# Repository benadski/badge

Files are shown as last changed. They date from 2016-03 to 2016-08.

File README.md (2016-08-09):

# Fri3d Camp Badge

Elk zichzelf respecterend hacker/maker/DIY kamp, _moet_ een eigen badge hebben. Zo ook Fri3d Camp :-)

## Concept

Bij het ontwerp van de badge voor Fri3d Camp zijn we vertrokken van drie principes:

1. Een hoge _hack_-baarheid.
2. Leerzaam voor beginners.
3. Interactief.

Daarom brengt de badge het Arduino platform samen met infra-rode stralen om een eenvoudig Fri3d Camp draadloos (IR) netwerk te maken.

Het Arduino platform laat iedereen toe om de software van de badge aan te passen, of er iets totaal anders mee te doen. Naast de badge-functie voor Fri3d Camp, brengen we alle andere mogelijke functionaliteit van de microcontroller naar buiten, zodat de badge, na het kamp, letterlijk kan dienen als jouw eigen Arduino ontwikkel-bord.

Aan de hand van de IR componenten en bijhorende software kunnen de elementaire aspecten van draadloze communicatie uitgelegd worden.

### Meta-Leerzaam

Dit ontwerp is mijn eerste SMD-gebaseerde project en het is op zich al een leerzame ervaring. Daarom bevat deze repository tevens een [design dagboek](design/dagboek.md) waarin ik alle stappen van het proces beschrijf.

## Hardware Design

Twee bestaande projecten kunnen beschouwd worden als de spreekwoordelijke ouders van de badge: 

* [Arduino Pro Micro - 3.3V/8MHz van Sparkfun](https://www.sparkfun.com/products/12587)
* [TV B Gone van Mitch Altman](https://cornfieldelectronics.com/tvbgone/tvbg.home.php)

Voeg nog een IR receiver en een RGB LED toe en je hebt alle basis componenten voor een leerzame, interactieve en zeer _hack_-bare Fri3d Camp badge!

## Software

Om zelf aan de slag te gaan met de [software](src/README.md) zo eenvoudig mogelijk te maken, was één van dé belangrijkste aspecten een makkelijke integratie met het Arduino software platform. De mogelijkheid om de badge te programmeren via de Arduino IDE door middel van louter een micro-USB kabel was daarom een noodzaak.

Om het Arduino platform nog verder zo veel mogelijk te gebruiken, hebben we ook gekozen om zo dicht mogelijk bij een bestaand Arduino bord te blijven en zo is de badge in essentie een [Arduino Mirco](https://www.arduino.cc/en/Main/ArduinoBoardMicro) geworden.

Je kan dus onmiddellijk aan de slag, zoals met elke andere Arduino. Daarnaast bevat deze [repository](src/README.md) enkele applicaties specifiek geschreven voor de Fri3d Camp badge, en dit naast een bibliotheek die het aanspreken van de extras makkelijk maakt. Zo vindt je (weldra) hier:

* dé Fri3d Camp 2016 app
* een implementatie van de TV B Gone applicatie van Mitch Altman
* ...

Als je zelf een nieuwe app maakt die op de Fri3d Camp badge werkt en op een andere, leuke manier gebruik maakt van de IR communicatie en de RGB LED of van andere componenten die je er zelf aan toegevoegd hebt, bezorg ons dan deze code en we voegen ze toe aan deze repository (pull request).

## Credits

De badge werd ontworpen door Christophe VG, samen met de hele Fri3d Camp organisatie, en uitgewerkt met de hulp van Dragan Subotic, Yannick Verbelen, Maarten Weyn, Willy De a Court, Anthony Liekens, Dries Deroeck, Jef Van Den Broeck, Toon Van de Putte,...

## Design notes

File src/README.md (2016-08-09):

# Fri3d Camp Badge Software

In deze sectie van de Fri3d Camp Badge repository vind je alle
software-gerelateerde zaken, gaande van de bootloader tot verschillende Arduino
sketches die je stap voor stap leren werken met de Fri3d Badge.

## Bootloader

Zonder een [bootloader](bootloader/), kan je zelf moeilijk aan de slag via de Arduino IDE.

## Alive

De eerste Arduino sketch die op onze badge werkte en aangaf dat ze werkte: It's [alive](alive/).

## TV B Fri3d

Niet op zijn minst als eerbetoon aan Mitch Altman en zijn TV B Gone, de Arduino implementatie ervan op de Fri3d Badge: [TV B Fri3d](tv-b-fri3d)!

## Examples

Als je de `Fri3dBadge/` folder kopieert (of linkt) in je sketch folder, kan je alle examples rechtstreeks in je Arduino IDE openen en op de Fri3d Camp Badge laden.

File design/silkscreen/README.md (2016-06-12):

# Adding Logo's to the Silkscreen

```bash
$ make
convert rombit.png -colors 2 -type bilevel +antialias rombit.bmp
convert fri3d.pdf fri3d.png
convert fri3d.png -colors 2 -type bilevel +antialias fri3d.bmp
rm fri3d.png
```

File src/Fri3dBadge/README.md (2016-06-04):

This folder should go in your Sketchbook/libraries folder. You can do this
using a symbolic link:

```bash
$ ln -s `pwd`/src/Fri3dBadge ~/Documents/Arduino/libraries/
```

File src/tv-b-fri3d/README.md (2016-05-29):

# TV B Fri3d

Aangezien de [TV B Gone](http://cornfieldelectronics.com/tvbgone/tvbg.home.php) één van de spreekwoordelijks ouders is van de Fri3d Badge, kan een implementatie van deze software niet ontbreken.

Het gebruiken van een Arduino om een "TV B Gone" te maken, is ook het onderwerp van een workshop van Mitch Altman zelf (zie: [http://cornfieldelectronics.com/cfe/projects/tvbg_arduino/tvbg_arduino_workshop.php](http://cornfieldelectronics.com/cfe/projects/tvbg_arduino/tvbg_arduino_workshop.php) voor meer info).

Deze versie is gebaseerd op eerder werk door Ken Shirriff. Mitch Altman heeft de code verder aangepast voor meerdere Arduino platformen, o.a. voor de "Adafruit's Flora", welke ook werkt op basis van de ATMega32u4.

## Aanpassingen

De code werkt niet "out-of-the-box" op de Fri3d Badge. Ze compileert prima,  maar we moeten nog wel enkele aanpassingen doen, omdat we andere pinnen (kunnen) gebruiken om de verschillende LEDs aan te sturen. Enerzijds is er de aansturing van de IR LEDs en anderszijds is er de status LED.

#### IR LED

In het geval van de Fri3d Badge is de pin om de IR LEDs aan te sturen (`IR_TX`) voorzien op pin `PF6`. In de code is ondersteuning voor Arduino/ATmega32u4 digitale pinnen "Digital Pin 3" of "Digital Pin 11" voorzien. Deze komen respectievelijk overeen met pin 18, `PD0`, en pin 12, `PB7 `(zie [https://www.arduino.cc/en/Hacking/PinMapping32u4](https://www.arduino.cc/en/Hacking/PinMapping32u4))

De code die hier relevant is:

```c
...
    // Fast PWM, setting top limit, divide by 8
    // Output to pin 3
#ifdef __AVR_ATmega32U4__
  #if (IRLED == 11)
    TCCR0A = _BV(COM0A1) | _BV(COM0A0) | _BV(WGM01) | _BV(WGM00);
  #elif (IRLED == 3)
    TCCR0A = _BV(COM0B1) | _BV(COM0B0) | _BV(WGM01) | _BV(WGM00);
  #else
    #error "IR LED must be on Leonardo digital pin 3 or 11."
  #endif
...  
```

Nader onderzoek leert dat dit tevens de twee pinnen zijn die op de ATmega32u4 kunnen gebruikt worden in een opstelling met `Timer0`. Zie [http://r6500.blogspot.be/2014/12/fast-pwm-on-arduino-leonardo.html](http://r6500.blogspot.be/2014/12/fast-pwm-on-arduino-leonardo.html), sectie over 'Single Slope PWM':
>Timer 0 has two compare channels A and B associated to two compare registers OCR0A and OCR0B. The two channels are linked to two hardware outputs OC0A and OC0B that are used as Arduino pins numbers 11 and 3.

Aangezien de Arduino implementatie voor de ATmega32 Beide pinnen zijn in ons design nog beschikbaar, zal het dus neerkomen op een aanpassing van het schema en de layout. Aangezien dit van de onderkant naar de bovenkant van de layout moet, zal het dus langs de onderkant moeten doorlopen. Gegeven de huidige layout, lijkt `PD0`, "Digital Pin 3", de beste keuze.

#### Status LED

The TV B Gone uses a status LED to indicate what it's doing. We don't have a simple LED on Fri3d Badge, but we have an RGB LED ;-)

De code die hier relevant is:

```c
// This function quickly pulses the visible LED (connected to PB0, pin 5)
// This will indicate to the user that a code is being transmitted
void quickflashLED( void ) {
  digitalWrite(LED, HIGH);
  delay_ten_us(3000);   // 30 millisec delay
  digitalWrite(LED, LOW);
}
```

Hier gaan we de RGB LED gebruiken, dus de code "moet" structureel aangepast worden, en drie verschillende pinnen aansturen. Oops, ook hier lopen we opnieuw _bijna_ tegen een slechte voorbereiding op: om de drie kleuren/pinnen te controleren hebben we opnieuw 3 PWM kanalen nodig. Gelukkig zijn de drie pinnen (`RGB_REG`, `RGB_GREEN` en `RGB_BLUE`) net aangesloten op drie pinnen met PWM support on "Digital Pins 5, 10 en 9". Een snelle test moet dit weldra bevestigen.

Wordt vervolgd...

## Fri3d Badge op Fri3d Camp 2016

Mitch Altman komt met zijn "Arduino for newbies" workshop naar Fri3d Camp, en wie weet werken jullie wel met jullie eigen badge tijdens deze workshop ;-) We sturen onze aanpassingen in ieder geval naar hem door ;-)

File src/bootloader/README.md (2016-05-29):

# Fri3d Camp Badge Bootloader

Een bootloader zorgt er voor dat de eerste software die op de microcontroller
de microcontroller toegankelijk maakt om er nieuwe software op te zetten zonder
een volledige programmerinfrastructuur. Concreet laat de Arduino bootloader toe
om via de Arduino IDE software te installeren op de microcontroller via de USB
kabel.

## Selecteren

Er zijn verschillende booloaders voor Arduino, maar slechts enkele komen in aanmerking voor onze microcontroller, de ATmega32u4.

We zijn vertrokken van de Arduino Micro Pro 3.3V vertrokken. Deze module werd ontworpen door Sparkfun en ze stellen ook een bootloader ter beschikking voor deze modules. We kunnen ze daarom ook hergebruiken. De bootloader voor deze module is een versie van de "caterina" bootloader.

Alle verschillende bootloaders zijn te vinden via [https://github.com/sparkfun/Arduino_Boards/tree/master/sparkfun/avr/bootloaders/caterina](https://github.com/sparkfun/Arduino_Boards/tree/master/sparkfun/avr/bootloaders/caterina)

Voorlopig hebben we na wat proberen gekozen voor de bootloader van de "[LilyPad USB](https://www.sparkfun.com/products/12049)". Deze module is ook gebaseerd op de ATmega32u4 en gebruikt ook de 3.3V opstelling aan 8MHz. Mogelijk zijn andere bootloaders ook mogelijk. We bekijken dit nog, maar voorlopig werkt deze keuze prima :-)

## Installeren

De Makefile in deze folder automatiseert de installatie aan de hand van de Atmel JTAGICE MkII programmer. Ze stuurt `avrdude` aan. Installatie van een bootloader vraagt twee stappen:

1. Het instellen van de `fuses` zodat de bootloader kan ingesteld worden.
2. Het effectief uploaden van de bootloader en het blokkeren ervan.

Wanneer je de Arduino IDE geïnstalleerd hebt, beschik je over een `boards.txt` bestand. Daarin vind je alle instellingen om de verschillende microcontrollers te programmeren. Je kan de instellingen die wij hier gebruiken ook hierin terugvinden:

Bv op Mac OS X kan je in de `Arduino.app` bundle het `boards.txt` bestand terugvinden als `Arduino.app/Contents/Java/hardware/arduino/avr/boards.txt`. Hierin vind je bv. een sectie over de Lilypad USB:

```
LilyPadUSB.bootloader.tool=avrdude
LilyPadUSB.bootloader.low_fuses=0xff
LilyPadUSB.bootloader.high_fuses=0xd8
LilyPadUSB.bootloader.extended_fuses=0xce
LilyPadUSB.bootloader.file=caterina-LilyPadUSB/Caterina-LilyPadUSB.hex
LilyPadUSB.bootloader.unlock_bits=0x3F
LilyPadUSB.bootloader.lock_bits=0x2F
```

We zien hier inderdaad dat de LilyPad voldoet aan onze mogelijkheden:

```
LilyPadUSB.build.mcu=atmega32u4
LilyPadUSB.build.f_cpu=8000000L
```

In het `boards.txt` bestand vinden we niet direct een andere module terug die de `atmega32u4` combineert met `8MHz`. Normaal gezien zou een "Arduino Micro Pro 3.3V" ook moeten lukken, maar dat is voorlopig nog niet bewezen ;-)

Om te installeren (met de zelfde programmer en instellingen als wij) volstaat een gewone `make`:

```bash
 make
*** unlocking MCU
!!! please toggle the power of the programmer
    Press any key to continue...
*** uploading bootloader
```

Normaal gezien zou de tussentijse reset van de programmer niet nodig mogen zijn, maar voorlopig geeft deze procedure de stabielste werking.

De twee commando's die onderliggend al het werk doen zijn:

```bash
$ avrdude -c jtag2isp -p atmega32u4 -P usb:5a:cb -b 19200 -e -U efuse:w:0xce:m -U hfuse:w:0xD8:m -U lfuse:w:0xFF:m -U lock:w:0x3f:m
$ avrdude -c jtag2isp -p atmega32u4 -P usb:5a:cb -b 19200 -e -U flash:w:Caterina-lilypadusb.hex -U lock:w:0x2F:m
```

## Zie ook ...

* [Arduino Hacking - Bootloader](https://www.arduino.cc/en/Hacking/Bootloader?from=Tutorial.Bootloader)
* [Sparkfun Tutorial on installing a bootloader](https://learn.sparkfun.com/tutorials/installing-an-arduino-bootloader)

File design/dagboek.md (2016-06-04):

# Design Dagboek

Aangezien dit [mijn](http://christophe.vg) eerste SMD-gebaseerde ontwerp is, zal het een fijne leerschool worden. Daarom wil ik deze hier documenteren, voor mezelf, maar ook voor iemand anders die het ook wel eens van naderbij wil bekijken.

## Klaar? ... Start ... Leer!

Ik heb gekozen voor
[Eagle](http://www.cadsoftusa.com/eagle-pcb-design-software/about-eagle/), de de facto standaard editor voor PCB ontwerp. De [gratis versie](http://www.cadsoftusa.com/download-eagle/freeware/) biedt alle mogelijkheden, met beperkingen waar je niet snel tegen loopt als beginner. De software is tevens beschikbaar voor alle courante platformen (Windows, Linux, Max OS X), wat niet het geval is met de meeste concurrenten.

Software kiezen is één, er mee werken... Gelukkig zijn er zeer goeie tutorials online te vinden:

* [https://learn.sparkfun.com/tutorials/how-to-install-and-setup-eagle](https://learn.sparkfun.com/tutorials/how-to-install-and-setup-eagle)
* [https://learn.sparkfun.com/tutorials/using-eagle-schematic](https://learn.sparkfun.com/tutorials/using-eagle-schematic)
* [https://learn.sparkfun.com/tutorials/using-eagle-board-layout](https://learn.sparkfun.com/tutorials/using-eagle-board-layout)
* [https://learn.sparkfun.com/tutorials/designing-pcbs-advanced-smd](https://learn.sparkfun.com/tutorials/designing-pcbs-advanced-smd)

## De schouders van reuzen

Het wiel uitvinden is al lang niet meer nodig in het koninkrijk van electronica. Er zijn heel veel designs te vinden die allemaal een deel van de puzzel kunnen zijn. Zo ben ik ook vertrokken van enkele grote puzzelstukken en heb die bij elkaar gebracht.

### Arduino Micro Pro 3.3V

De basis van het ontwerp is de Arduino Micro Pro in de versie die op 3.3V werkt. Deze bevat alle minimale eisen die we stelden aan het ontwerp, in een redelijk eenvoudig samen te stellen geheel. De microcontroller, de ATMEGA32u4, bevat USB connectiviteit, waardoor eenvoudige ondersteuning voor de Arduino IDE en programmaring mogelijk wordt.

[https://www.sparkfun.com/products/12587](https://www.sparkfun.com/products/12587)

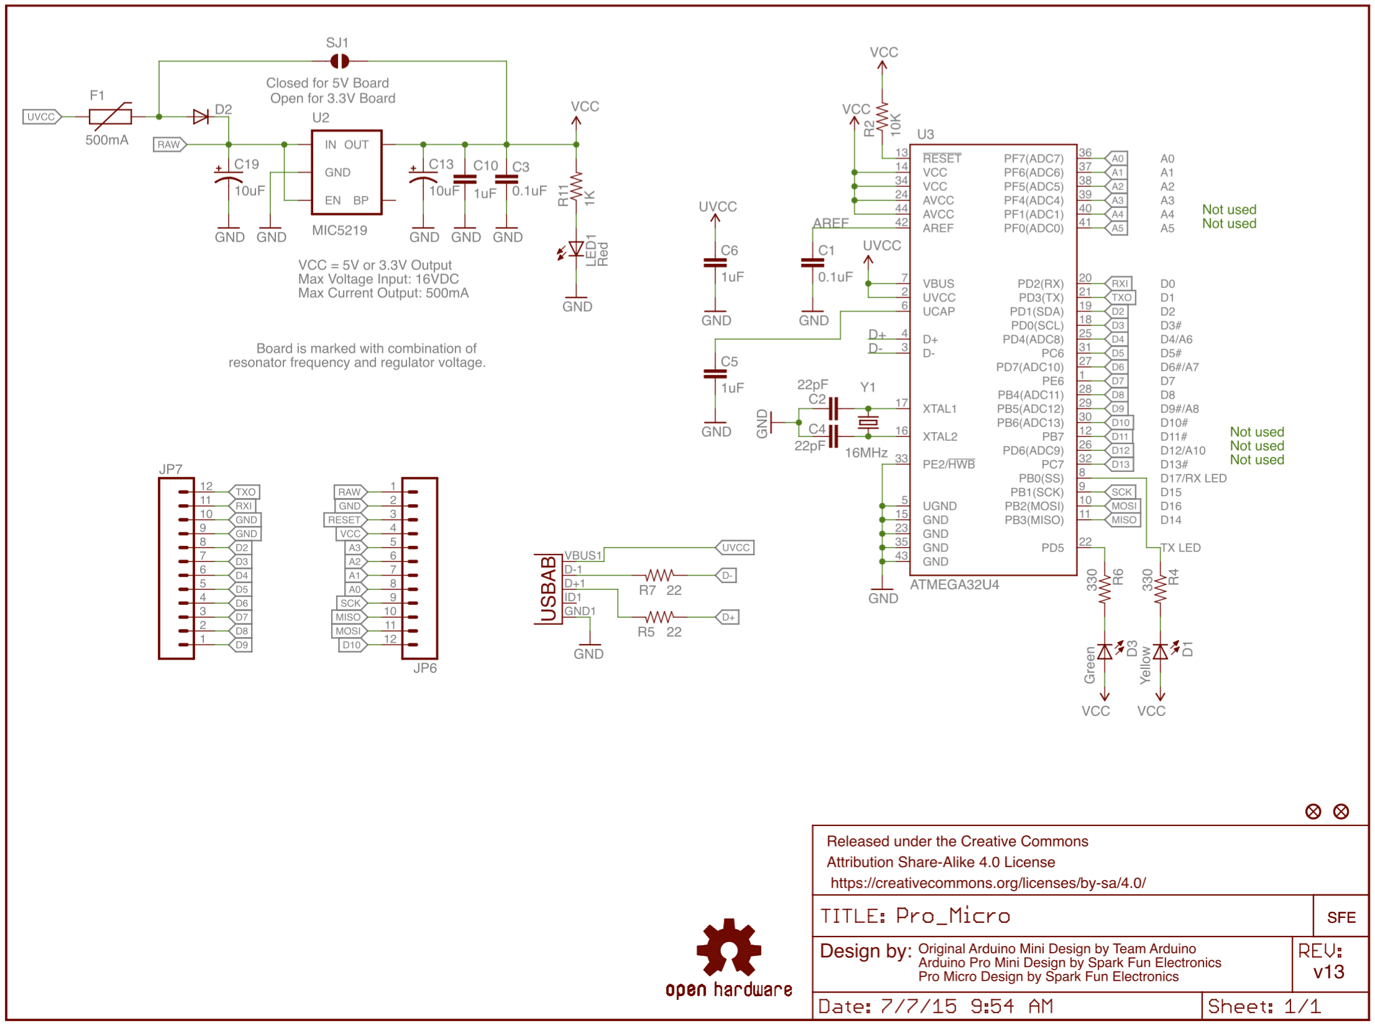
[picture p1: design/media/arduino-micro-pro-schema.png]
Arduino Micro Pro


### TV B Gone

De initiële plannen om een draadloze netwerk-verbinding te incorporeren, strandden toen we de prijzen zagen voor de RF modules. Gelukkig bestaat er een "goedkoop" alternatief, die relatief dezelfde technologie introduceert, op een veel eenvoudigere en betaalbare manier: infra-rode (IR) stralen.

En als we aan IR denken, komen we al snel uit bij Mitch Altmans TV B Gone. Deze IR zendende oplossing kan prima dienen als referentie design voor deze functionaliteit.

[https://learn.adafruit.com/tv-b-gone-kit/download](https://learn.adafruit.com/tv-b-gone-kit/download) 

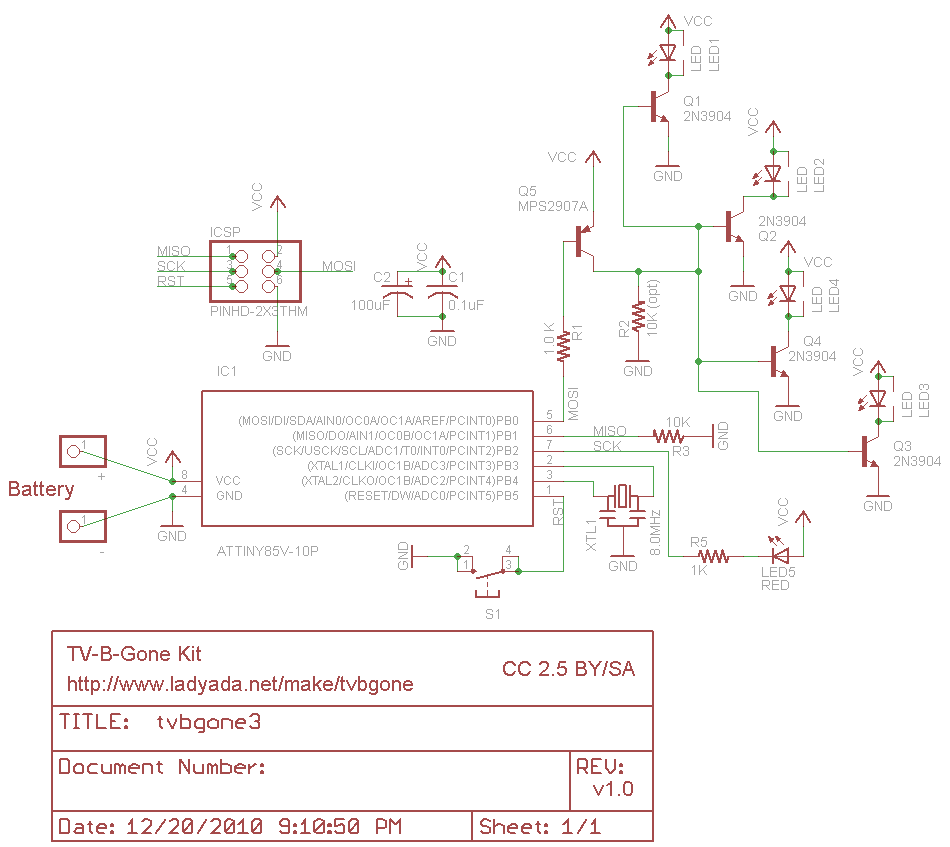
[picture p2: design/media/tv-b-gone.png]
TV B Gone


### LiPo oplaad circuit

De IR LEDs trekken al snel een stroom die boven de mogelijkheden liggen van een coin cell batterij. We konden gaan voor 2 AAA batterijen, maar dan wordt de badge al snel log en zwaar. Daarom proberen we bij het initiële design te vertrekken van een herlaadbare LiPo batterij.

Om deze te kunnen opladen, hebben we een integratie nodig met de inkomende USB voeding. Gelukkig bestaat ook daarvoor een bijna de facto oplossing en is ook het omringende oplaad-circuit mooi gedocumenteerd.

[https://learn.sparkfun.com/tutorials/lipo-usb-charger-hookup-guide](https://learn.sparkfun.com/tutorials/lipo-usb-charger-hookup-guide)

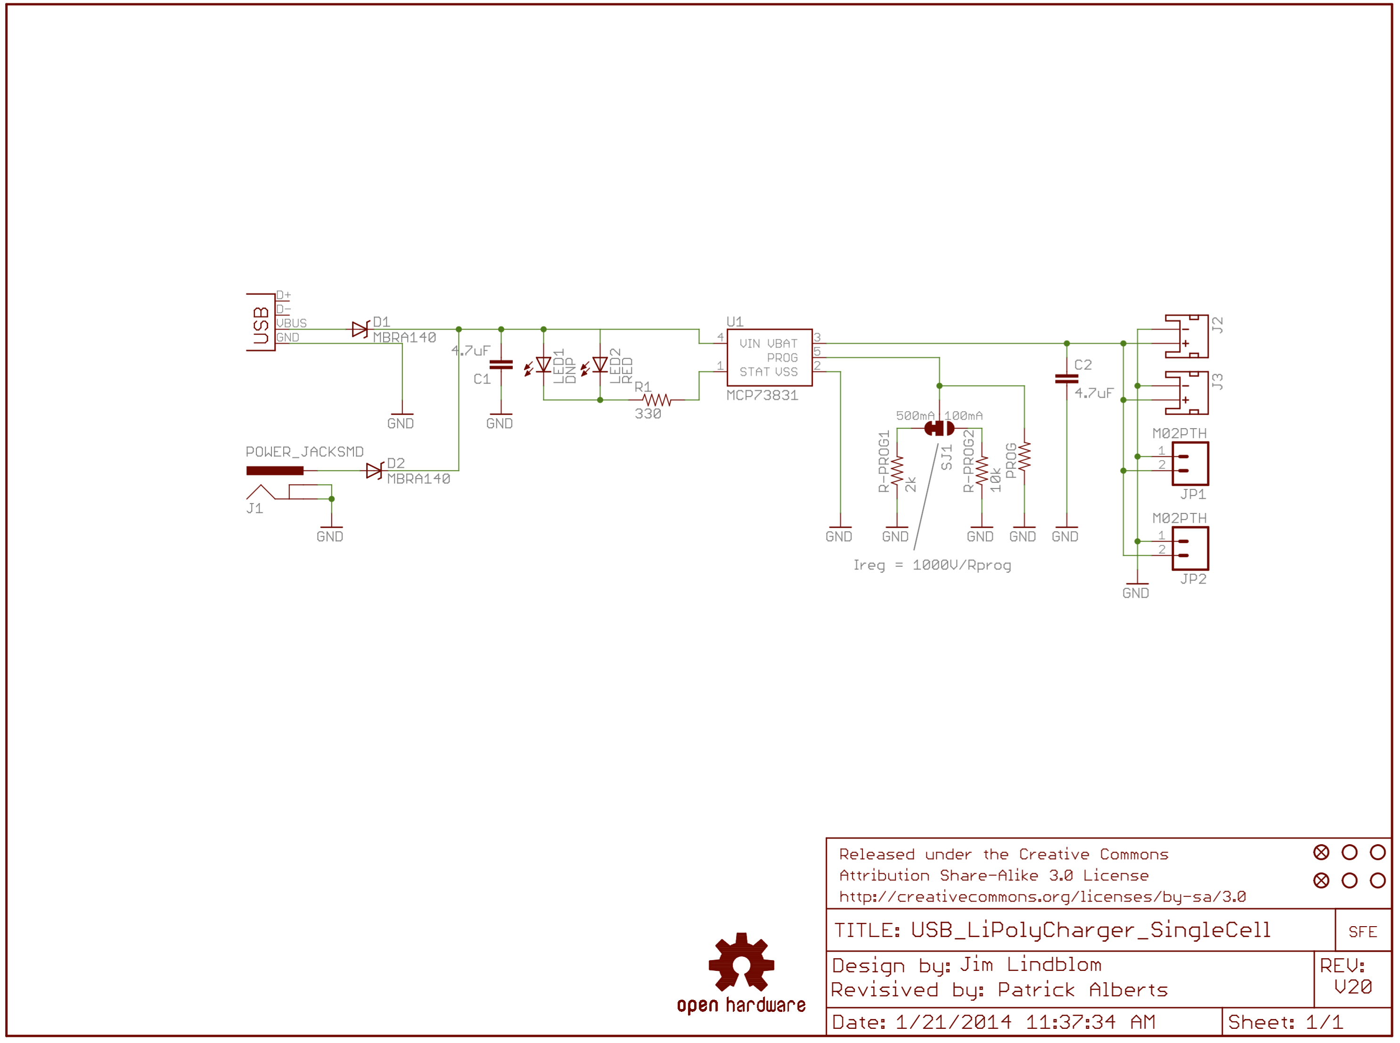
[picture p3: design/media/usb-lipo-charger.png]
USB LiPo Charger


### Fri3d Badge Schema versie 1

De combinatie van de drie voorgaand vermelde referentie designs, gecombineerd met nog een knopje, RGB LED en IR ontvanger, levert ons ...

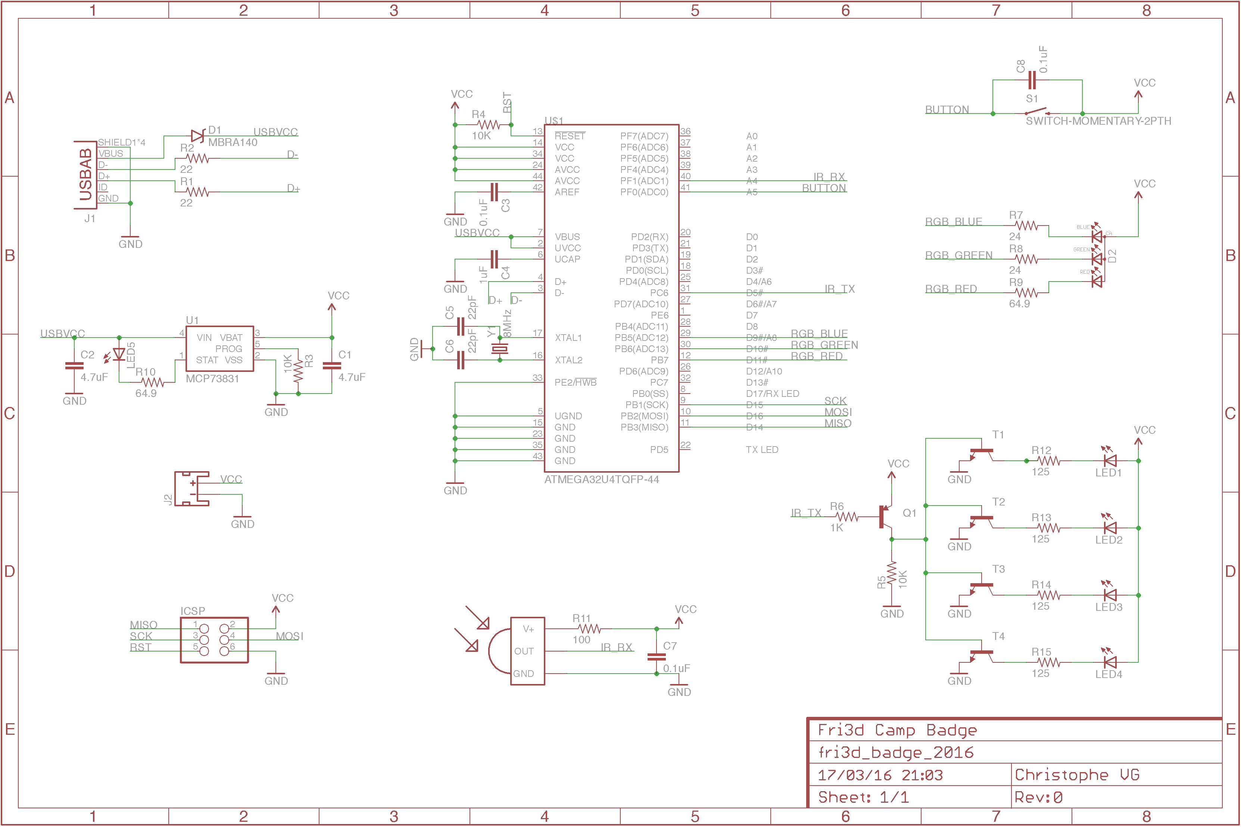
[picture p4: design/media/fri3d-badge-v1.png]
Fri3d Badge Schema versie 1


## Eerste optimalisaties

Met versie 1 onder de arm op naar enkele hulplijnen. Met het oog op zo veel mogelijk automatisering van de productie, zijn enkele aspecten zeer belangrijk:

1. Hoe minder componenten, hoe minder er kan fout gaan.
2. Hoe minder verschillende componenten, hoe meer dat er geautomatiseerd kan verlopen.

Met dat motto in gedachte werden volgende aanpassingen aan versie 1 doorgevoerd:

1. Vervanging van de PNP + NPN constructie voor de IR LEDs door een enkele N-channel MOSFET.
2. Vervanging van weerstanden door combinaties van dezelfde weerstanden (e.g. 2 weerstanden van 220&ohm; in parallel is ongeveer gelijk aan één van 100&ohm; enz)
3. Enkele fouten en redundante componenten werden bijgewerkt/verwijderd.

### Fri3d Badge Schema versie 2

En dat levert ons een versie op waarmee ik aan de slag kan om de layout van de PCB te maken...

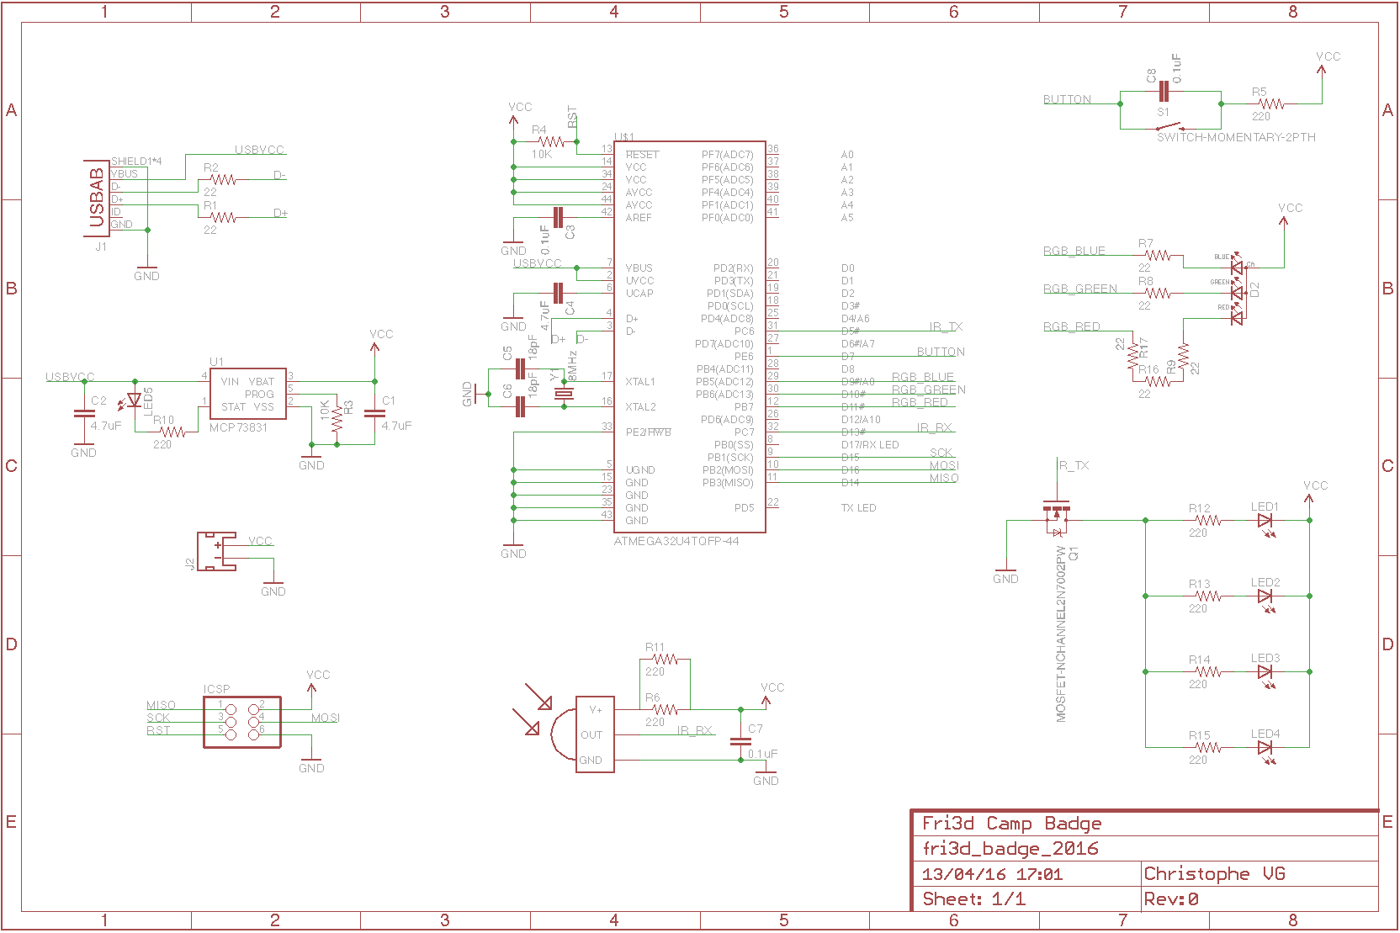
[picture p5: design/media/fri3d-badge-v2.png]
Fri3d Badge Schema versie 2


## PCB Layout

De Fri3d Badge heeft op het eerste zicht al één belangrijke eigenschap: zijn vorm is geen klassieke PCB-vorm, want we willen ze de vorm geven van het logo.

Na het tekenen van de omtrek ga je aan de slag om de componenten een plek te geven. Hierbij probeer je zo veel mogelijk logische blokken te maken en het aantal kruisende lijnen (air wires) te minimaliseren.

De PCB zal opgebouwd worden uit twee lagen, de voor- en achterkant van de badge. Op de achterkant komt hoofdzakelijk de oplaadbare batterij en de bijhorende connector. Centraal op de voorkant komt de microcontroller en daarrond de verschillende functionele componenten: IR LEDs, IR receiver, RGB LED, knop, laadcircuit, USB connector, ICSP connector.

Na een avondje zwoegen kom je dan, met wat hulp, tot een eerste PCB layout:

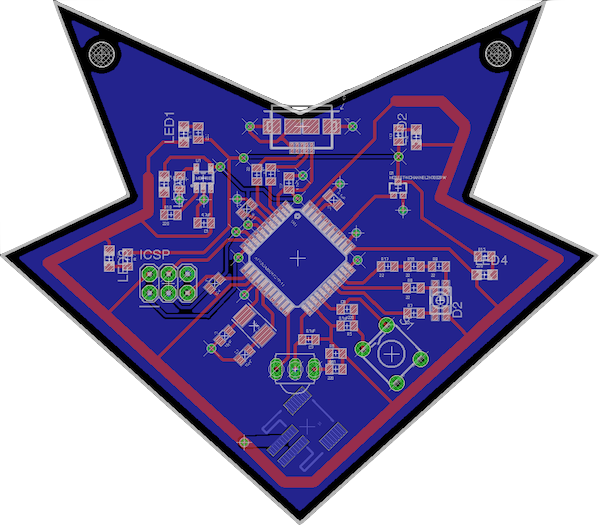
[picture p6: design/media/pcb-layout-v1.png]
Fri3d Badge Layout versie 1


Enkele tips:

* Creëer op de onderkant een groot vlak en verbindt dit met GND. Nu hoef je van de bovenkant slechts een via te maken en je hebt directe toegang tot de GND. Zie het grote blauwe vlak op de layout hierboven.
* De zelfde truc kan je bij een meer-dan-twee lagen PCB ook doen voor VCC, maar die luxe hebben we hier niet. Daarom truc nr. 2: maak een dikke VCC-omranding! Niet meer gewoon te bereiken met een via, maar wel langs een kort baantje naar de buitenzijde van de PCB.

### Eerste Prototype(s)

En dan is het tijd om de virtuele wereld van Eagle te verlaten en echte prototypes te maken. Met een koffer vol componenten trokken we naar het electronica-lab van de Erasmus Hoge School om zelf PCBs te etsen en te voorzien van componenten - een hele onderneming.

**Wordt vervolgd...**

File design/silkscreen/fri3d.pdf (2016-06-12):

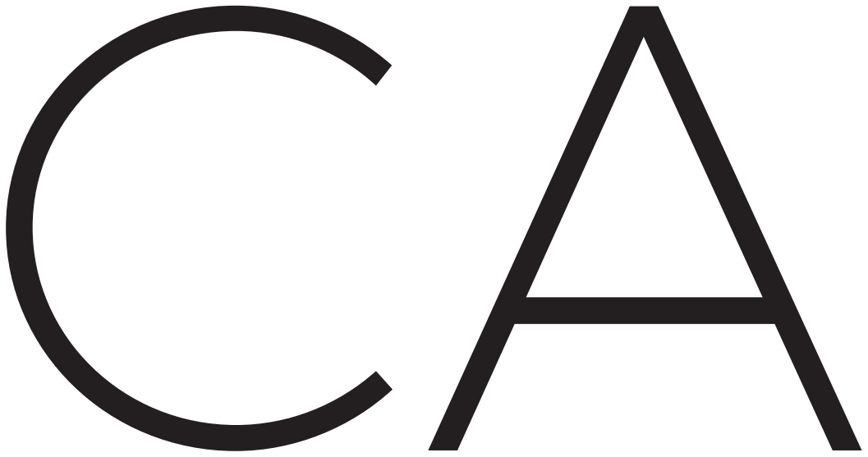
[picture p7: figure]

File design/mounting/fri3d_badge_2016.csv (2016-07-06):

%,Origin,Offset,X,Y,,
% theoretical offset 7,7
65535,0,5.5,6.5,,
%,Stack,Offset,Stack,X,Y,
% offsets for MCU in tray
% x = -8.8 + 6 = -2.8
% y=   8.6 - 6 =  2.6
65535,1,0,-2.8,2.6,
65535,1,1,0,0,
65535,1,2,0,0,
65535,1,3,0,0,
65535,1,4,0,0,
65535,1,5,0,0,
65535,1,6,0,0,
65535,1,7,0,0,
65535,1,8,0,0,
65535,1,9,0,0,
65535,1,10,0,0,
65535,1,11,0,0,
65535,1,12,0,0,
65535,1,13,0,0,
65535,1,14,0,0,
65535,1,15,0,0,
%,Feeding,Set,Stack,Feed,Rate,
65535,2,0,18,
65535,2,1,4,
65535,2,2,4,
65535,2,3,4,
65535,2,4,4,
65535,2,5,4,
65535,2,6,4,
65535,2,7,4,
65535,2,8,4,
65535,2,9,4,
65535,2,10,4,
65535,2,11,4,
65535,2,12,4,
65535,2,13,8,
65535,2,14,8,
65535,2,15,8,
%,Jointed,Board,X,Y
65535,3,0,69.87,0,0,0,0
65535,3,78.47,0,0,0,0,0
65535,3,78.47,69.87,0,0,0,0
%,Head,Stack,X,Y,R,H,skip,Ref,Comment,
0,5,0,0,0,0,0,0,
1,1,1,27.11,41.45,90,1.3,0,C1,4.7uF-0805
2,1,1,30.50,43.95,-180,1.3,0,C2,4.7uF-0805
3,1,2,43.49,44.15,45,1.3,0,C3,0.1uF-0805
4,1,1,32.38,42.10,-180,1.3,0,C4,4.7uF-0805
5,1,3,28.08,19.42,-90,1.3,0,C5,18pF-0805
6,1,3,28.18,22.25,-90,1.3,0,C6,18pF-0805
7,1,2,50.47,23.59,0,1.3,0,C7,0.1uF-0805
8,1,2,39.61,23.41,-90,1.3,0,C8,0.1uF-0805
9,1,4,21.74,45.50,180,1.3,0,CHRGLED,CHRG-CHIPLED_0805
10,1,5,24.18,52.31,0,1.3,0,IRLED1,-CHIPLED_0805
11,1,5,55.42,52.40,0,1.3,0,IRLED2,-CHIPLED_0805
12,1,5,15.35,34.30,90,1.3,0,IRLED3,-CHIPLED_0805
13,1,5,64.77,33.40,-90,1.3,0,IRLED4,-CHIPLED_0805
0,1,0,0,0,0,0,0,
14,2,0,39.68,35.62,-45,1.3,0,MCU,ATMEGA32U4TQFP-44-TQFP44
0,5,0,0,0,0,0,0,
15,1,6,49.47,50.84,0,1.3,0,MOSFET,N-CHANNEL-MOSFET-BSS138-SOT23-3
16,1,7,35.90,45.96,-45,1.3,0,R1,22-0805
17,1,7,37.39,44.41,-45,1.3,0,R2,22-0805
18,1,8,23.83,45.81,0,1.3,0,R3,10K-0805
19,1,8,29.63,31.46,-180,1.3,0,R4,10K-0805
20,1,9,44.31,18.06,0,1.3,0,R5,220-0805
21,1,9,52.99,23.55,-180,1.3,0,R6,220-0805
22,1,9,51.09,28.36,-90,1.3,0,R7,220-0805
23,1,9,51.08,30.96,-90,1.3,0,R8,220-0805
24,1,9,57.96,33.27,-90,1.3,0,R9,220-0805
25,1,9,22.65,41.52,-90,1.3,0,R10,220-0805
26,1,9,55.14,23.56,-180,1.3,0,R11,220-0805
27,1,9,26.33,52.47,-180,1.3,0,R12,220-0805
28,1,9,53.22,52.67,-180,1.3,0,R13,220-0805
29,1,9,15.21,36.37,90,1.3,0,R14,220-0805
30,1,9,64.80,35.87,-90,1.3,0,R15,220-0805
31,1,9,54.59,33.27,-90,1.3,0,R16,220-0805
32,1,9,51.08,33.27,-90,1.3,0,R17,220-0805
33,1,8,35.60,27.20,0,1.3,0,R18,10K-0805
34,2,11,57.20,29.15,90,1.3,0,U$4,AVAGO-RGB-LED
35,1,10,27.04,46.40,0,1.3,0,XFMR,MCP73831-SOT23-5

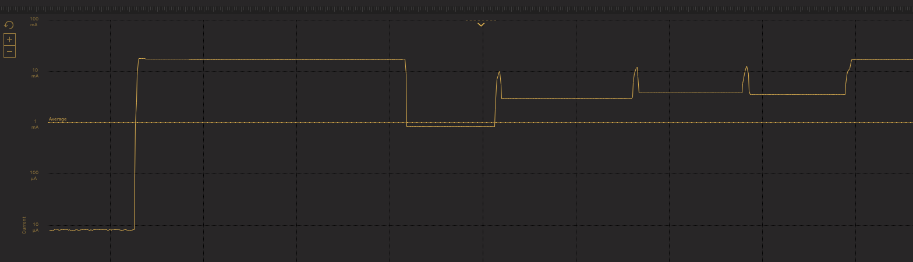
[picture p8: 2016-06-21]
design/media/sleep-mode-rgb.png

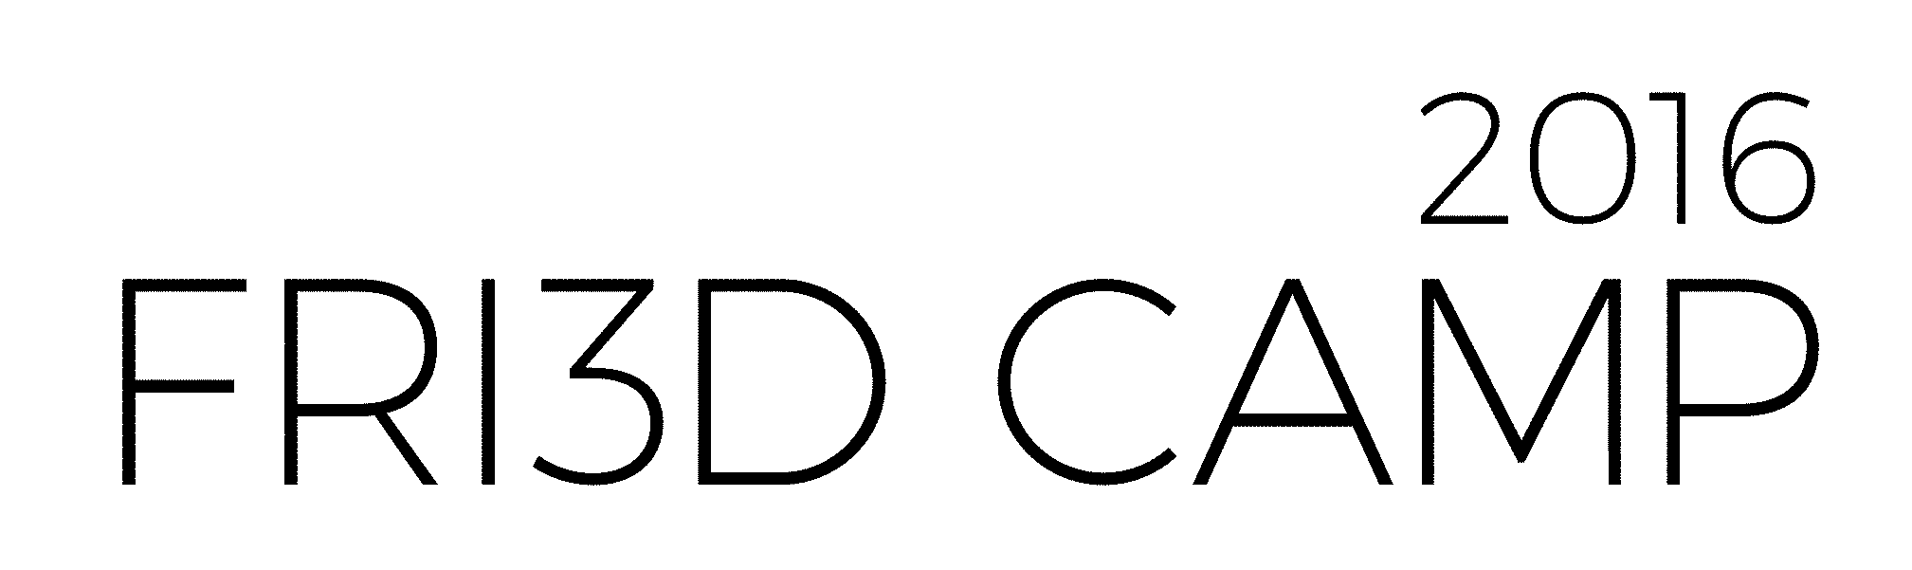
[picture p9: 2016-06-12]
design/silkscreen/fri3d.bmp

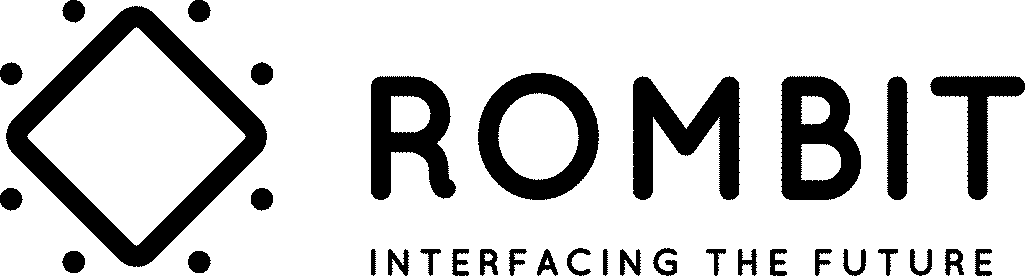
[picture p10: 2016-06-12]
design/silkscreen/rombit.bmp

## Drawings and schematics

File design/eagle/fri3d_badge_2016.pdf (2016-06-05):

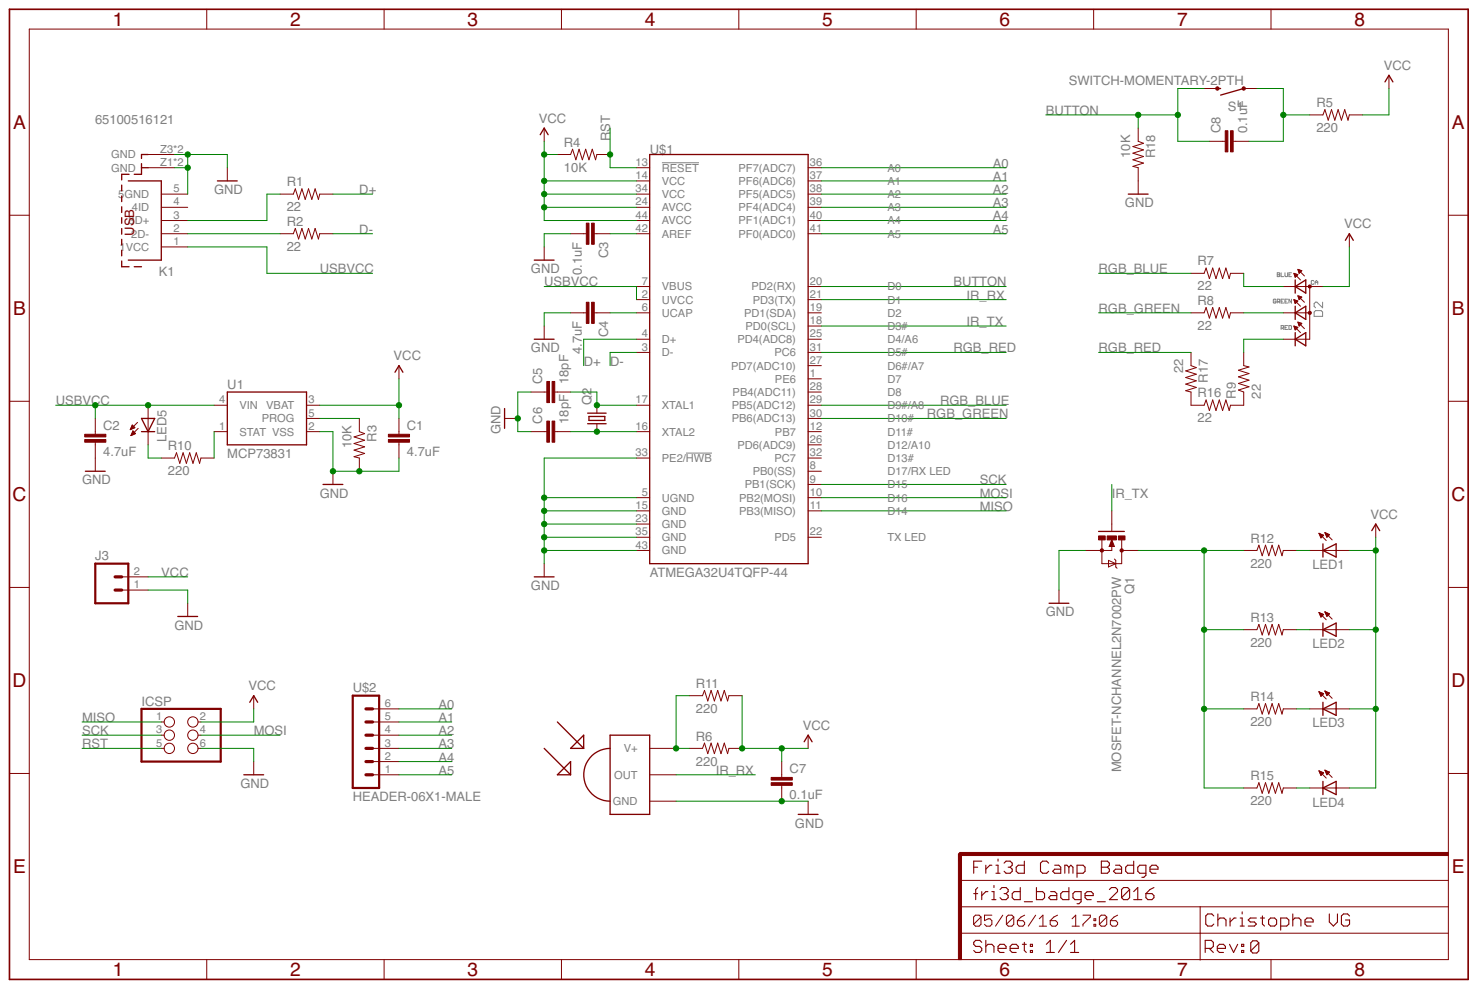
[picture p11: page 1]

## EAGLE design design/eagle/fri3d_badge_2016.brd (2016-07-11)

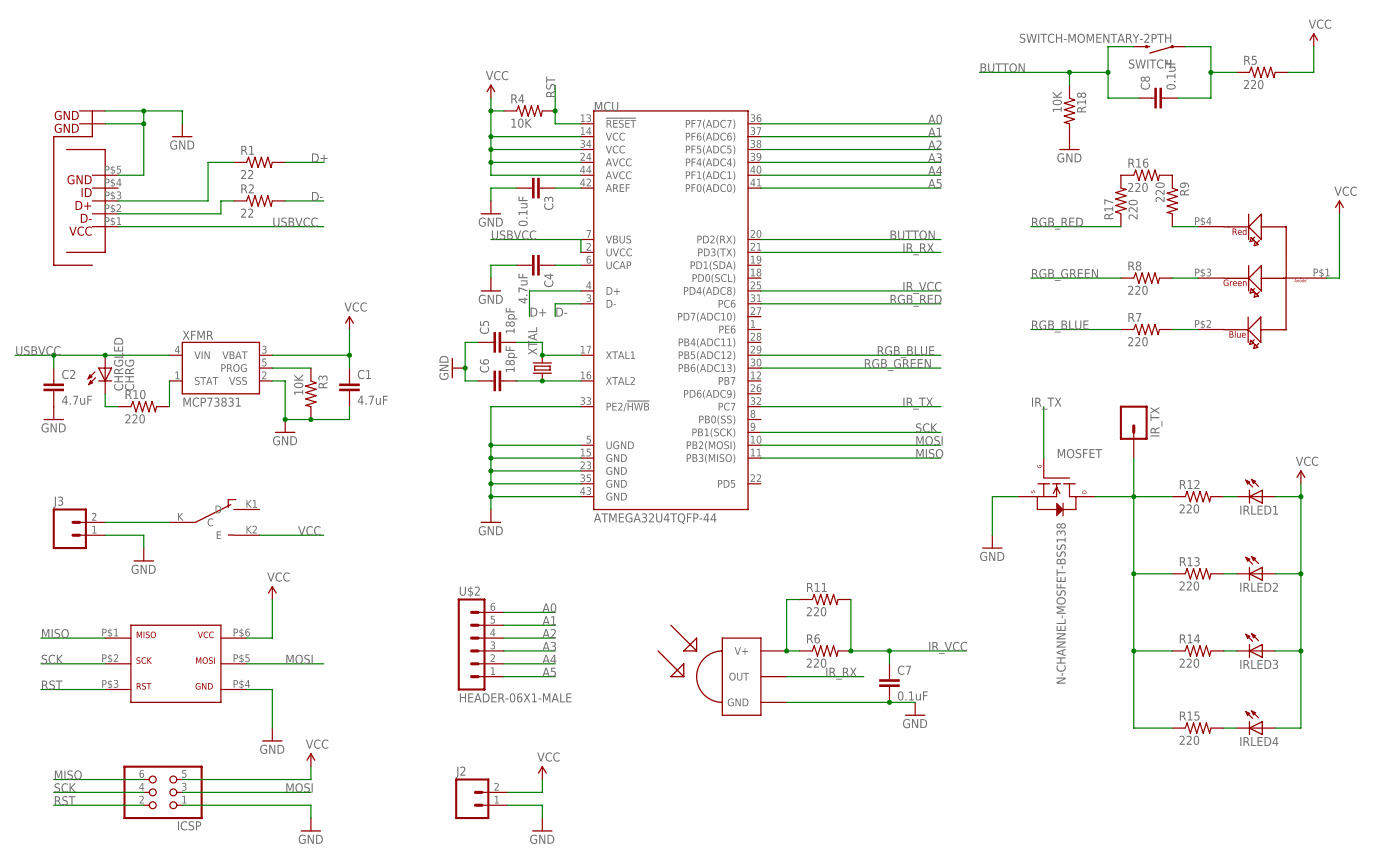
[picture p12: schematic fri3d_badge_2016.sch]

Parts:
C1, C2, C4: 4.7uF; 0805
C3, C7, C8: 0.1uF; 0805
C5, C6: 18pF; 0805
CHRGLED: CHRG; CHIPLED_0805
ICSP: PINHD-2X3; 2X03
IRLED1, IRLED2, IRLED3, IRLED4: LEDCHIPLED_0805; CHIPLED_0805
IR_TX: M01PTH; 1X01
J2: M02PTH; 1X02
J3: M02JST-PTH-2; JST-2-PTH
MCU: ATMEGA32U4TQFP-44; TQFP44
MOSFET: N-CHANNEL-MOSFET-BSS138; SOT23-3
R1, R2: 22; 0805
R3, R4, R18: 10K; 0805
R5, R6, R7, R8, R9, R10, R11, R12, R13, R14, R15, R16, R17: 220; 0805
SWITCH: SWITCH-MOMENTARY-2PTH; TACTILE-PTH
U$2: HEADER-06X1-MALE; 06X1-PTH
U$3: TSOP4838; TSOP18XX
U$4: DRAGAN-PERSONAL_AVAGO-RGB-LED
U$5: OCTA-CORE_MCIRO-USB2MOUSER; OCTA-CORE_MICRO-USB2
U$6: SLIDE-SWITCH
U$7: OCTA-CORE_TC2030-IDC
XFMR: MCP73831; SOT23-5
XTAL: CRYSTALHC49S; HC49/S

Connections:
A0: MCU.36 (PF7(ADC7)), U$2.6
A1: MCU.37 (PF6(ADC6)), U$2.5
A2: MCU.38 (PF5(ADC5)), U$2.4
A3: MCU.39 (PF4(ADC4)), U$2.3
A4: MCU.40 (PF1(ADC1)), U$2.2
A5: MCU.41 (PF0(ADC0)), U$2.1
BUTTON: C8.1, MCU.20 (PD2(RX)), R18.1, SWITCH.3 (2)
D+: MCU.4 (D+), R1.2
D-: MCU.3 (D-), R2.2
GND: C1.2, C2.2, C3.2, C4.2, C5.1, C6.1, C7.2, ICSP.1, J2.1, J3.1, MCU.5 (UGND), MCU.15 (GND), MCU.23 (GND), MCU.33 (PE2/!HWB), MCU.35 (GND), MCU.43 (GND), MOSFET.2 (S), R3.2, R18.2, U$3.GND, U$5.P$5, U$5.P$6, U$5.P$7, U$5.P$8, U$5.P$9, U$5.P$10, U$5.P$11, U$5.P$12, U$5.P$13, U$7.P$4, XFMR.2 (VSS)
IR_RX: MCU.21 (PD3(TX)), U$3.OUT
IR_TX: MCU.32 (PC7), MOSFET.1 (G)
IR_VCC: C7.1, MCU.25 (PD4(ADC8)), R6.2, R11.2
MISO: ICSP.6, MCU.11 (PB3(MISO)), U$7.P$1
MOSI: ICSP.3, MCU.10 (PB2(MOSI)), U$7.P$5
unnamed: R2.1, U$5.P$2
unnamed: R1.1, U$5.P$3
unnamed: C8.2, R5.1, SWITCH.1
unnamed: C4.1, MCU.6 (UCAP)
unnamed: R3.1, XFMR.5 (PROG)
unnamed: CHRGLED.C, R10.1
unnamed: C3.1, MCU.42 (AREF)
unnamed: C5.2, MCU.17 (XTAL1), XTAL.2
unnamed: C6.2, MCU.16 (XTAL2), XTAL.1
unnamed: R6.1, R11.1, U$3.VCC (V+)
unnamed: R9.1, R16.2
unnamed: R16.1, R17.2
unnamed: IRLED1.C, R12.2
unnamed: IRLED2.C, R13.2
unnamed: IRLED3.C, R14.2
unnamed: IRLED4.C, R15.2
unnamed: J3.2, U$6.K (C)
unnamed: R9.2, U$4.P$4
unnamed: R8.2, U$4.P$3
unnamed: R7.2, U$4.P$2
unnamed: R10.2, XFMR.1 (STAT)
unnamed: IR_TX.1, MOSFET.3 (D), R12.1, R13.1, R14.1, R15.1
RGB_BLUE: MCU.29 (PB5(ADC12)), R7.1
RGB_GREEN: MCU.30 (PB6(ADC13)), R8.1
RGB_RED: MCU.31 (PC6), R17.1
RST: ICSP.2, MCU.13 (!RESET), R4.2, U$7.P$3
SCK: ICSP.4, MCU.9 (PB1(SCK)), U$7.P$2
USBVCC: C2.1, CHRGLED.A, MCU.2 (UVCC), MCU.7 (VBUS), U$5.P$1, XFMR.4 (VIN)
VCC: C1.1, ICSP.5, IRLED1.A, IRLED2.A, IRLED3.A, IRLED4.A, J2.2, MCU.14 (VCC), MCU.24 (AVCC), MCU.34 (VCC), MCU.44 (AVCC), R4.1, R5.2, U$4.P$1, U$6.K2 (E), U$7.P$6, XFMR.3 (VBAT)

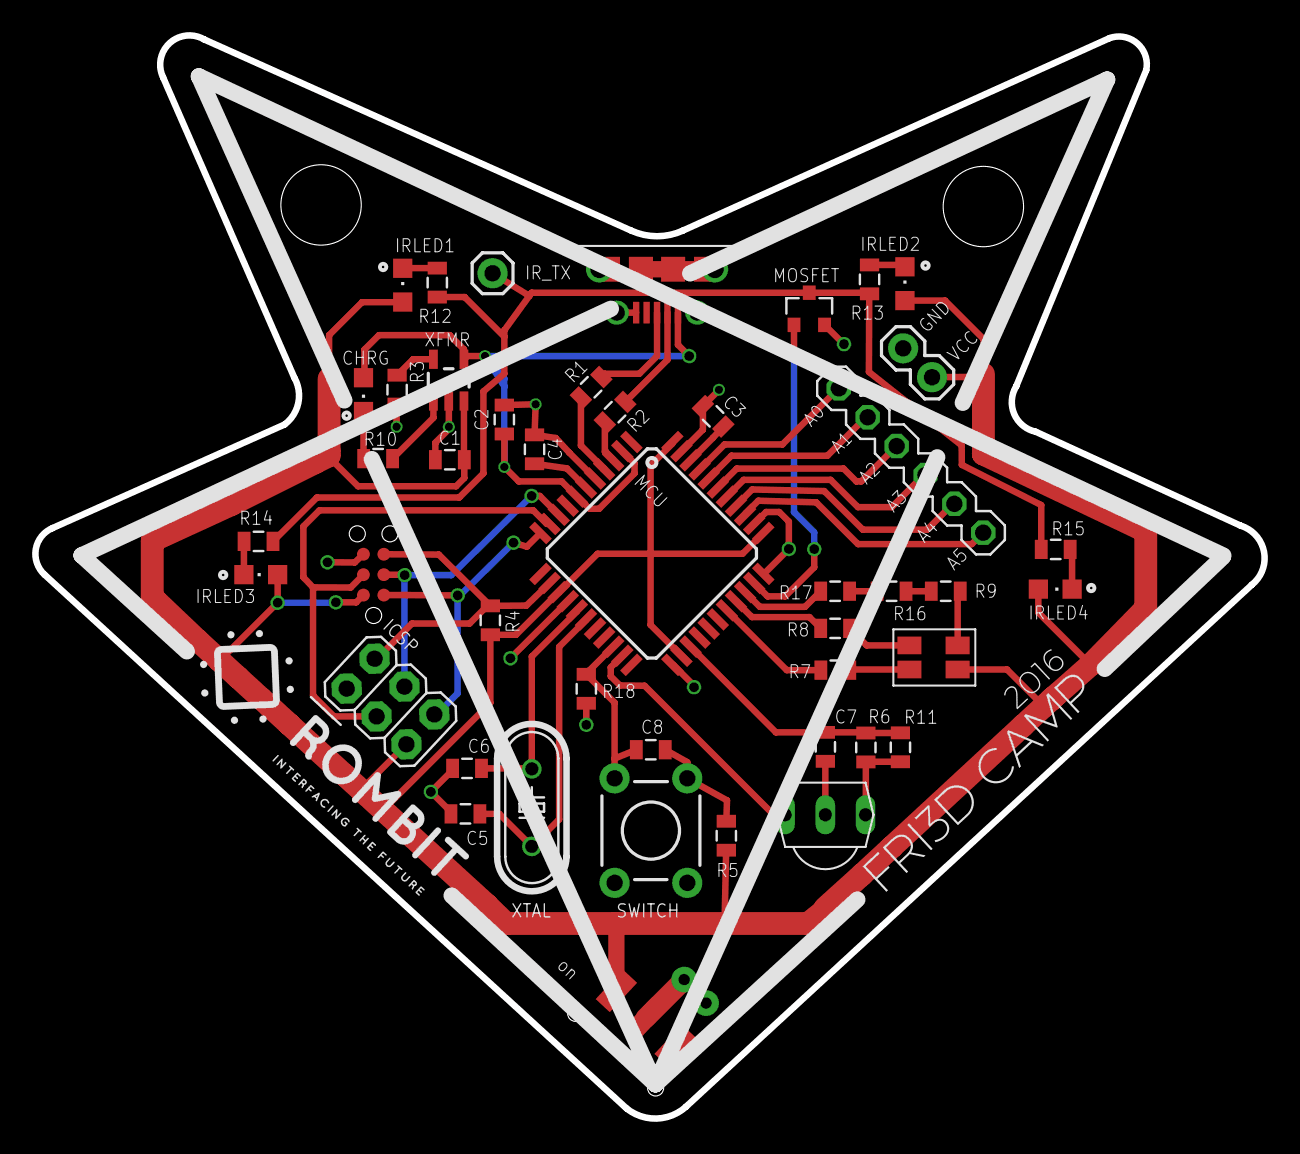
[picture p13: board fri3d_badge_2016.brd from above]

Board: 2 copper layers, 76.5 x 67.4 mm, 46 parts (1 on the bottom side), 44 nets.

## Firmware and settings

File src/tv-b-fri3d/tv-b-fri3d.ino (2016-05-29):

/*
TV-B-Gone for Arduino version 1.6.5, Sept 2 2015
Ported to Arduino by Ken Shirriff=
http://www.arcfn.com/2009/12/tv-b-gone-for-arduino.html

The hardware for this project uses an Arduino:
 Connect an IR LED to pin 3 (RLED).
 Connect a visible LED to pin 13 (or use builtin LED in some Arduinos).
 Connect a pushbutton between pin 2 (TRIGGER) and ground.
 Pin 5 (REGIONSWITCH) is floating for North America, or wired to ground for Europe.

The original code is:
TV-B-Gone Firmware version 1.2
 for use with ATtiny85v and v1.2 hardware
 (c) Mitch Altman + Limor Fried 2009
 Last edits, August 16 2009


 I added universality for EU or NA,
 and Sleep mode to Ken's Arduino port
      -- Mitch Altman  18-Oct-2010
 Thanks to ka1kjz for the code for adding Sleep
      <http://www.ka1kjz.com/561/adding-sleep-to-tv-b-gone-code/>


 With some code from:
 Kevin Timmerman & Damien Good 7-Dec-07


 13-September-2015
 Now also works with Arduino Leonardo
    Added code from TV-B-Gone sketch for Adafruit's Flora board
    32u4 microcontroller by Phillip Burgess for Adafruit Industries


 2-September-2015
 Updated definitions for:
      extern PGM_P *NApowerCodes[] PROGMEM;
      extern PGM_P *EUpowerCodes[] PROGMEM;
 to:
      extern "C" const struct IrCode * const NApowerCodes[] PROGMEM;
      extern "C" const struct IrCode * const EUpowerCodes[] PROGMEM;
 so that the sketch will compile with Arduino 1.6.5 software.


 Distributed under Creative Commons 2.5 -- Attib & Share Alike

*/

#include "main.h"
#include <avr/sleep.h>


void xmitCodeElement(uint16_t ontime, uint16_t offtime, uint8_t PWM_code );
void quickflashLEDx( uint8_t x );
void delay_ten_us(uint16_t us);
void quickflashLED( void );
uint8_t read_bits(uint8_t count);


#define putstring_nl(s) Serial.println(s)
#define putstring(s) Serial.print(s)
#define putnum_ud(n) Serial.print(n, DEC)
#define putnum_uh(n) Serial.print(n, HEX)


/*
This project transmits a bunch of TV POWER codes, one right after the other,
 with a pause in between each.  (To have a visible indication that it is
 transmitting, it also pulses a visible LED once each time a POWER code is
 transmitted.)  That is all TV-B-Gone does.  The tricky part of TV-B-Gone
 was collecting all of the POWER codes, and getting rid of the duplicates and
 near-duplicates (because if there is a duplicate, then one POWER code will
 turn a TV off, and the duplicate will turn it on again (which we certainly
 do not want).  I have compiled the most popular codes with the
 duplicates eliminated, both for North America (which is the same as Asia, as
 far as POWER codes are concerned -- even though much of Asia USES PAL video)
 and for Europe (which works for Australia, New Zealand, the Middle East, and
 other parts of the world that use PAL video).

 Before creating a TV-B-Gone Kit, I originally started this project by hacking
 the MiniPOV kit.  This presents a limitation, based on the size of
 the Atmel ATtiny2313 internal flash memory, which is 2KB.  With 2KB we can only
 fit about 7 POWER codes into the firmware's database of POWER codes.  However,
 the more codes the better! Which is why we chose the ATtiny85 for the
 TV-B-Gone Kit.

 This version of the firmware has the most popular 100+ POWER codes for
 North America and 100+ POWER codes for Europe. You can select which region
 to use by soldering a 10K pulldown resistor.
*/


/*
This project is a good example of how to use the AVR chip timers.
*/


extern "C" const struct IrCode * const NApowerCodes[] PROGMEM;
extern "C" const struct IrCode * const EUpowerCodes[] PROGMEM;
extern uint8_t num_NAcodes, num_EUcodes;


/* This function is the 'workhorse' of transmitting IR codes.
 Given the on and off times, it turns on the PWM output on and off
 to generate one 'pair' from a long code. Each code has ~50 pairs! */
void xmitCodeElement(uint16_t ontime, uint16_t offtime, uint8_t PWM_code )
{
#ifdef __AVR_ATmega32U4__
  TCNT0 = 0;
#else
  TCNT2 = 0;
#endif
  if(PWM_code) {
    pinMode(IRLED, OUTPUT);
    // Fast PWM, setting top limit, divide by 8
    // Output to pin 3
#ifdef __AVR_ATmega32U4__
  #if (IRLED == 11)
    TCCR0A = _BV(COM0A1) | _BV(COM0A0) | _BV(WGM01) | _BV(WGM00);
  #elif (IRLED == 3)
    TCCR0A = _BV(COM0B1) | _BV(COM0B0) | _BV(WGM01) | _BV(WGM00);
  #else
    #error "IR LED must be on Leonardo digital pin 3 or 11."
  #endif
    TCCR0B = _BV(WGM02) | _BV(CS01);
#else
    TCCR2A = _BV(COM2A0) | _BV(COM2B1) | _BV(WGM21) | _BV(WGM20);
    TCCR2B = _BV(WGM22) | _BV(CS21);
#endif
  }
  else {
    // However some codes dont use PWM in which case we just turn the IR
    // LED on for the period of time.
    digitalWrite(IRLED, HIGH);
  }


  // Now we wait, allowing the PWM hardware to pulse out the carrier
  // frequency for the specified 'on' time
  delay_ten_us(ontime);


  // Now we have to turn it off so disable the PWM output
#ifdef __AVR_ATmega32U4__
  TCCR0A = 0;
  TCCR0B = 0;
#else
  TCCR2A = 0;
  TCCR2B = 0;
#endif
  // And make sure that the IR LED is off too (since the PWM may have
  // been stopped while the LED is on!)
  digitalWrite(IRLED, LOW);


  // Now we wait for the specified 'off' time
  delay_ten_us(offtime);
}


/* This is kind of a strange but very useful helper function
 Because we are using compression, we index to the timer table
 not with a full 8-bit byte (which wastes memory space) but 2, 3, or 4 bits.
 Once code_ptr is set up to point to the right part of memory,
 this function will let us read 'count' bits at a time which
 it does by reading a byte into 'bits_r' and then buffering it. */


uint8_t bitsleft_r = 0;
uint8_t bits_r=0;
PGM_P code_ptr;


// we cant read more than 8 bits at a time so dont try!
uint8_t read_bits(uint8_t count)
{
  uint8_t i;
  uint8_t tmp=0;


  // we need to read back count bytes
  for (i=0; i<count; i++) {
    // check if the 8-bit buffer we have has run out
    if (bitsleft_r == 0) {
      // in which case we read a new byte in
      bits_r = pgm_read_byte(code_ptr++);
      // and reset the buffer size (8 bites in a byte)
      bitsleft_r = 8;
    }
    // remove one bit
    bitsleft_r--;
    // and shift it off of the end of 'bits_r'
    tmp |= (((bits_r >> (bitsleft_r)) & 1) << (count-1-i));
  }
  // return the selected bits in the LSB part of tmp
  return tmp;
}


/*
The C compiler creates code that will transfer all constants into RAM when
 the microcontroller resets.  Since this firmware has a table (powerCodes)
 that is too large to transfer into RAM, the C compiler needs to be told to
 keep it in program memory space.  This is accomplished by the macro PROGMEM
 (this is used in the definition for powerCodes).  Since the C compiler assumes
 that constants are in RAM, rather than in program memory, when accessing
 powerCodes, we need to use the pgm_read_word() and pgm_read_byte macros, and
 we need to use powerCodes as an address.  This is done with PGM_P, defined
 below.
 For example, when we start a new powerCode, we first point to it with the
 following statement:
 PGM_P thecode_p = pgm_read_word(powerCodes+i);
 The next read from the powerCode is a byte that indicates the carrier
 frequency, read as follows:
 const uint8_t freq = pgm_read_byte(code_ptr++);
 After that is a byte that tells us how many 'onTime/offTime' pairs we have:
 const uint8_t numpairs = pgm_read_byte(code_ptr++);
 The next byte tells us the compression method. Since we are going to use a
 timing table to keep track of how to pulse the LED, and the tables are
 pretty short (usually only 4-8 entries), we can index into the table with only
 2 to 4 bits. Once we know the bit-packing-size we can decode the pairs
 const uint8_t bitcompression = pgm_read_byte(code_ptr++);
 Subsequent reads from the powerCode are n bits (same as the packing size)
 that index into another table in ROM that actually stores the on/off times
 const PGM_P time_ptr = (PGM_P)pgm_read_word(code_ptr);
 */


uint16_t ontime, offtime;
uint8_t i,num_codes, Loop;
uint8_t region;
uint8_t startOver;


#define FALSE 0
#define TRUE 1


void setup()   {
  Serial.begin(9600);


#ifdef __AVR_ATmega32U4__
  // Timer0 is used on Arduino Leonardo (there is no Timer2).
  // This means delay(), millis() etc. are not available,
  // but they're currently not being used by this code.
  TIMSK0 = 0; // Disable Timer0 interrupt
  TCCR0A = 0;
  TCCR0B = 0;
#else
  TCCR2A = 0;
  TCCR2B = 0;
#endif


  digitalWrite(LED, LOW);
  digitalWrite(IRLED, LOW);
  digitalWrite(DBG, LOW);     // debug
  pinMode(LED, OUTPUT);
  pinMode(IRLED, OUTPUT);
  pinMode(DBG, OUTPUT);       // debug
  pinMode(REGIONSWITCH, INPUT);
  pinMode(TRIGGER, INPUT);
  digitalWrite(REGIONSWITCH, HIGH); //Pull-up
  digitalWrite(TRIGGER, HIGH);


  delay_ten_us(5000);            // Let everything settle for a bit


  // determine region
  if (digitalRead(REGIONSWITCH)) {
    region = NA;
    DEBUGP(putstring_nl("NA"));
  }
  else {
    region = EU;
    DEBUGP(putstring_nl("EU"));
  }


  // Indicate how big our database is
  DEBUGP(putstring("\n\rNA Codesize: ");
  putnum_ud(num_NAcodes);
  );
  DEBUGP(putstring("\n\rEU Codesize: ");
  putnum_ud(num_EUcodes);
  );


  // Tell the user what region we're in  - 3 flashes is NA, 6 is EU
  delay_ten_us(50000); // wait 0.5 sec
  quickflashLEDx(3);
  if (region == EU) {
    quickflashLEDx(3);
  }
}


void sendAllCodes() {
Start_transmission:
  // startOver will become TRUE if the user pushes the Trigger button while transmitting the sequence of all codes
  startOver = FALSE;


  // determine region from REGIONSWITCH: 1 = NA, 0 = EU
  if (digitalRead(REGIONSWITCH)) {
    region = NA;
    num_codes = num_NAcodes;
  }
  else {
    region = EU;
    num_codes = num_EUcodes;
  }


  // Blink the visible LED to show that we're starting to transmit OFF codes
  quickflashLED();


  // for every POWER code in our collection
  for (i=0 ; i < num_codes; i++) {
    PGM_P data_ptr;


    // print out the code # we are about to transmit
    DEBUGP(putstring("\n\r\n\rCode #: ");
    putnum_ud(i));


    // point to next POWER code, from the right database
    if (region == NA) {
      data_ptr = (PGM_P)pgm_read_word(NApowerCodes+i);
    }
    else {
      data_ptr = (PGM_P)pgm_read_word(EUpowerCodes+i);
    }


    // print out the address in ROM memory we're reading
    DEBUGP(putstring("\n\rAddr: ");
    putnum_uh((uint16_t)data_ptr));


    // Read the carrier frequency from the first byte of code structure
    const uint8_t freq = pgm_read_byte(data_ptr++);
    // set OCR for Timer1 to output this POWER code's carrier frequency
#ifdef __AVR_ATmega32U4__
    OCR0A = freq;
    OCR0B = freq / 3; // 33% duty cycle
#else
    OCR2A = freq;
    OCR2B = freq / 3; // 33% duty cycle
#endif


    // Print out the frequency of the carrier and the PWM settings
    DEBUGP(putstring("\n\rOCR1: ");
    putnum_ud(freq);
    );
    DEBUGP(uint16_t x = (freq+1);
    putstring("\n\rFreq: ");
    putnum_ud(F_CPU/8/x);
    );
       //DEBUGP(putstring("\n\rAddr: ");
       //putnum_uh((uint16_t)data_ptr));


    // Get the number of pairs, the second byte from the code struct
    const uint8_t numpairs = pgm_read_byte(data_ptr++);
    DEBUGP(putstring("\n\rOn/off pairs: ");
    putnum_ud(numpairs));
       //DEBUGP(putstring("\n\rAddr: ");
       //putnum_uh((uint16_t)data_ptr));


    // Get the number of bits we use to index into the timer table
    // This is the third byte of the structure
    const uint8_t bitcompression = pgm_read_byte(data_ptr++);
    DEBUGP(putstring("\n\rCompression: ");
    putnum_ud(bitcompression);
    putstring("\n\r"));


    // Get pointer (address in memory) to pulse-times table
    // The address is 16-bits (2 byte, 1 word)
       //DEBUGP(putstring("\n\rdata_ptr: ");
       //putnum_uh((uint16_t)data_ptr));
    PGM_P time_ptr = (PGM_P)pgm_read_word(data_ptr);
       //DEBUGP(putstring("\n\rtime_ptr: ");
       //putnum_uh((uint16_t)time_ptr));
    data_ptr+=2;
       //DEBUGP(putstring("\n\rdata_ptr: ");
       //putnum_uh((uint16_t)data_ptr));
    code_ptr = (PGM_P)pgm_read_word(data_ptr);
       //DEBUGP(putstring("\n\rcode_ptr: ");
       //putnum_uh((uint16_t)code_ptr));


    // Transmit all codeElements for this POWER code
    // (a codeElement is an onTime and an offTime)
    // transmitting onTime means pulsing the IR emitters at the carrier
    // frequency for the length of time specified in onTime
    // transmitting offTime means no output from the IR emitters for the
    // length of time specified in offTime


#if 0
    // print out all of the pulse pairs
    for (uint8_t k=0; k<numpairs; k++) {
      uint8_t ti;
      ti = (read_bits(bitcompression)) * 4;
      // read the onTime and offTime from the program memory
      ontime = pgm_read_word(time_ptr+ti);
      offtime = pgm_read_word(time_ptr+ti+2);
      DEBUGP(putstring("\n\rti = ");
      putnum_ud(ti>>2);
      putstring("\tPair = ");
      putnum_ud(ontime));
      DEBUGP(putstring("\t");
      putnum_ud(offtime));
    }
    continue;
#endif


    // For EACH pair in this code....
          //DEBUGP(putstring("\n\r");
          //putstring("\n\r=========================");
          //);
    cli();
    for (uint8_t k=0; k<numpairs; k++) {
      uint16_t ti;


      // Read the next 'n' bits as indicated by the compression variable
      // The multiply by 4 because there are 2 timing numbers per pair
      // and each timing number is one word long, so 4 bytes total!
      ti = (read_bits(bitcompression)) * 4;


      // read the onTime and offTime from the program memory
      ontime = pgm_read_word(time_ptr+ti);  // read word 1 - ontime
      offtime = pgm_read_word(time_ptr+ti+2);  // read word 2 - offtime
          //DEBUGP(putstring("\n\rti = ");
          //putnum_ud(ti>>2);
          //putstring("\tPair = ");
          //putnum_ud(ontime));
          //DEBUGP(putstring("\t");
          //putnum_ud(offtime));
      // transmit this codeElement (ontime and offtime)
      xmitCodeElement(ontime, offtime, (freq!=0));
    }
    sei();


    //Flush remaining bits, so that next code starts
    //with a fresh set of 8 bits.
    bitsleft_r=0;


    // delay 205 milliseconds before transmitting next POWER code
    delay_ten_us(20500);


    // visible indication that a code has been output.
    quickflashLED();


    // if user is pushing Trigger button, stop transmission
    if (digitalRead(TRIGGER) == 0) {
      startOver = TRUE;
      break;
    }
  }


  if (startOver) goto Start_transmission;
  while (Loop == 1);


  // flash the visible LED on PB0  8 times to indicate that we're done
  delay_ten_us(65500); // wait maxtime
  delay_ten_us(65500); // wait maxtime
  quickflashLEDx(8);

}




void loop() {
  sleepNow();
  // if the user pushes the Trigger button and lets go, then start transmission of all POWER codes
  if (digitalRead(TRIGGER) == 0) {
    delay_ten_us(3000);  // delay 30ms
    if (digitalRead(TRIGGER) == 1) {
      sendAllCodes();
    }
  }
}




/****************************** LED AND DELAY FUNCTIONS ********/




// This function delays the specified number of 10 microseconds
// it is 'hardcoded' and is calibrated by adjusting DELAY_CNT
// in main.h Unless you are changing the crystal from 8mhz, dont
// mess with this.
void delay_ten_us(uint16_t us) {
  uint8_t timer;
  while (us != 0) {
    // for 8MHz we want to delay 80 cycles per 10 microseconds
    // this code is tweaked to give about that amount.
    for (timer=0; timer <= DELAY_CNT; timer++) {
      NOP;
      NOP;
    }
    NOP;
    us--;
  }
}




// This function quickly pulses the visible LED (connected to PB0, pin 5)
// This will indicate to the user that a code is being transmitted
void quickflashLED( void ) {
  digitalWrite(LED, HIGH);
  delay_ten_us(3000);   // 30 millisec delay
  digitalWrite(LED, LOW);
}


// This function just flashes the visible LED a couple times, used to
// tell the user what region is selected
void quickflashLEDx( uint8_t x ) {
  quickflashLED();
  while(--x) {
    delay_ten_us(15000);     // 150 millisec delay between flahes
    quickflashLED();
  }
}




/****************************** SLEEP and WAKE FUNCTIONS ********/
// from kaqkjz:
// http://www.ka1kjz.com/561/adding-sleep-to-tv-b-gone-code/

void sleepNow()
{
  set_sleep_mode(TRIGGER);                    // sleep mode is set here

  sleep_enable();                             // enables the sleep bit in the mcucr register

  attachInterrupt(0, wakeUpNow, LOW);         // use interrupt 0 (pin 2) and run function
  // wakeUpNow when pin 2 gets LOW

  sleep_mode();                               // here the device is actually put to sleep!!
  // THE PROGRAM CONTINUES FROM HERE ON WAKE

  sleep_disable();                            // first thing after waking, disable sleep

  detachInterrupt(0);                         // disables int 0 as the wakeupnow code will
                                              // not be executed during normal runtime
}

void wakeUpNow()
{
  // any needed wakeup code can be placed here
}

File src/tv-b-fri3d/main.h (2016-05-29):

#include <avr/pgmspace.h>


/*
2-September-2015
Updated definition for 
     struct IrCode {
so that the sketch will compile with Arduino 1.6.5 software.
Also: add conditional define for changing DELAY_CNT, 
      since the new Arduino software compiles to make the delay_ten_us() function execute too quickly.

*/


// The TV-B-Gone for Arduino can use
//   either the EU or the NA database of POWER CODES
// EU is for Europe, Middle East, Australia, New Zealand, and some countries in Africa and South America
// NA is for North America, Asia, and the rest of the world not covered by EU

// Two regions!
#define NA 1
#define EU 0

// What pins do what
#define DBG 12
#define LED 13
#define IRLED 3
#define TRIGGER 2
#define REGIONSWITCH 5  // add a 1K pull-down resistor from Pin 5 to ground for EU (blank for NA)

// Lets us calculate the size of the NA/EU databases
#define NUM_ELEM(x) (sizeof (x) / sizeof (*(x)));

// set define to 0 to turn off debug output
#define DEBUG 0
#define DEBUGP(x) if (DEBUG == 1) { x ; }

// Shortcut to insert single, non-optimized-out nop
#define NOP __asm__ __volatile__ ("nop")

// Arduino software that is newer than V1.0 needs a different value for DELAY_CNT
// set ARD_VER_10X to 1 for Arduino software V1.0.x
// set ARD_VER to 0 for newer versions of Arduino software (such as V1.6.5)
#define ARD_VER_10X 0

// DELAY_CNT is used for delay_ten_us() for timing ontime and offtime values
// Tweak this if neccessary to change timing for accuracy (which must be done empirically)
#if ARD_VER_10X
# define DELAY_CNT 25
#else
# define DELAY_CNT 30
#endif

// Makes the codes more readable. the OCRA is actually
// programmed in terms of 'periods' not 'freqs' - that
// is, the inverse!
#define freq_to_timerval(x) (F_CPU / 8 / x - 1)

// The structure of compressed code entries
struct IrCode {
  const uint8_t timer_val;
  const uint8_t numpairs;
  const uint8_t bitcompression;
  const uint16_t * const times;
  const uint8_t * const codes;
};

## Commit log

2016-03-14 added initial/draft schematic design
    [fri3d_badge_2016.sch]
2016-03-15 added missing cap+resistor on IR Receiver
    [fri3d_badge_2016.sch]
2016-03-16 update of design based on feedback by Dragan
    [fri3d_badge_2016.sch]
2016-03-18 added resistors for IR LEDs
    [fri3d_badge_2016.sch]
2016-04-13 update to version 2 of design
    [fri3d_badge_2016.sch]
2016-04-16 added board design, outline and initial placing
    [fri3d_badge_2016.brd]
2016-05-19 created first version (draft) PCB layout
    [fri3d_badge_2016.brd, fri3d_badge_2016.sch]
2016-05-23 layout tweaks -> v2
    [fri3d_badge_2016.brd, fri3d_badge_2016.sch]
2016-05-29 fixed wrongly connected IR LED net
    [fri3d_badge_2016.brd, fri3d_badge_2016.sch]
2016-05-29 ignoring gerber output files
2016-05-31 moved eagle files in project folder
    [fri3d_badge_2016.brd, fri3d_badge_2016.sch]
2016-05-31 added datasheet for RGB LED
2016-06-04 added button support + example
2016-06-04 added PCB layout v1
2016-06-05 added header for Analog pins A0-5
    [fri3d_badge_2016.brd, fri3d_badge_2016.sch]
2016-06-05 fixed IR receiver and button Arduino pins
    [fri3d_badge_2016.brd, fri3d_badge_2016.sch]
2016-06-05 added switch and draft silkscreen
    [fri3d_badge_2016.brd, fri3d_badge_2016.sch]
2016-06-05 changed resistors on RGB LED to 220 (to test)
    [fri3d_badge_2016.brd, fri3d_badge_2016.sch]
2016-06-06 fixed RGB LED footprint (+draft silk)
    [fri3d_badge_2016.brd, fri3d_badge_2016.sch]
2016-06-06 fixed USB connector (Mouser)
    [fri3d_badge_2016.brd, fri3d_badge_2016.sch]
2016-06-06 fixed switch footprint
    [fri3d_badge_2016.brd, fri3d_badge_2016.sch]
2016-06-06 replaced ICSP header with Tag Connect pads
    [fri3d_badge_2016.brd, fri3d_badge_2016.sch]
2016-06-06 fixed DRC issues
    [fri3d_badge_2016.brd, fri3d_badge_2016.sch]
2016-06-06 cleaned up silk
    [fri3d_badge_2016.brd]
2016-06-06 redid Tag Connect mapping (same layout)
    [fri3d_badge_2016.brd, fri3d_badge_2016.sch]
2016-06-06 added Arduino pin mapping + Tag Connect Datasheet
2016-06-07 added first stab at sponsor logo
    [fri3d_badge_2016.brd]
2016-06-12 added silkscreen generation files
2016-06-12 added Fri3d Camp 2016 logo + silkscreen clean up
    [fri3d_badge_2016.brd]
2016-06-19 updated pin for button to correct (new) one
    [Fri3dBadge.cpp]
2016-06-21 added interrupt driven button change handling
2016-06-21 initialise RGB LED to black
2016-06-21 added support for going to sleep… deeply ;-)
2016-06-22 IR powered by pin, added headers, cleaned up silk
    [fri3d_badge_2016.brd, fri3d_badge_2016.sch]
2016-06-24 attached IR/MOSFET to correct pin for IRremote
    [fri3d_badge_2016.brd, fri3d_badge_2016.sch]
2016-07-04 fixed MOSFET footprint + added dots for diodes
    [fri3d_badge_2016.brd, fri3d_badge_2016.sch]
2016-07-04 added header for IR_TX
    [fri3d_badge_2016.brd, fri3d_badge_2016.sch]
2016-07-04 added mounting ULP export script + initial config
    [fri3d_badge_2016.csv]
2016-07-04 fixed incorrect MOSFET footprint
    [fri3d_badge_2016.csv]
2016-07-06 removed not-placed components, added RGB LED
    [fri3d_badge_2016.csv]
2016-07-10 moved IR_TX test header
    [fri3d_badge_2016.brd]
2016-07-11 final silkscreen touch-ups
    [fri3d_badge_2016.brd, fri3d_badge_2016.sch]
2016-07-11 fixed bad font on backside
    [fri3d_badge_2016.brd]
2016-08-06 renamed license/ to info/ for case-insensitive FSs
2016-08-09 added comment about millis() rollover ;-)
2016-08-09 fixed (really) too small random INTERVAL part
    [camp.ino]

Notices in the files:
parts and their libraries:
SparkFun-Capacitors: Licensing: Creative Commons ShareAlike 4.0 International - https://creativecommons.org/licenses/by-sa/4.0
